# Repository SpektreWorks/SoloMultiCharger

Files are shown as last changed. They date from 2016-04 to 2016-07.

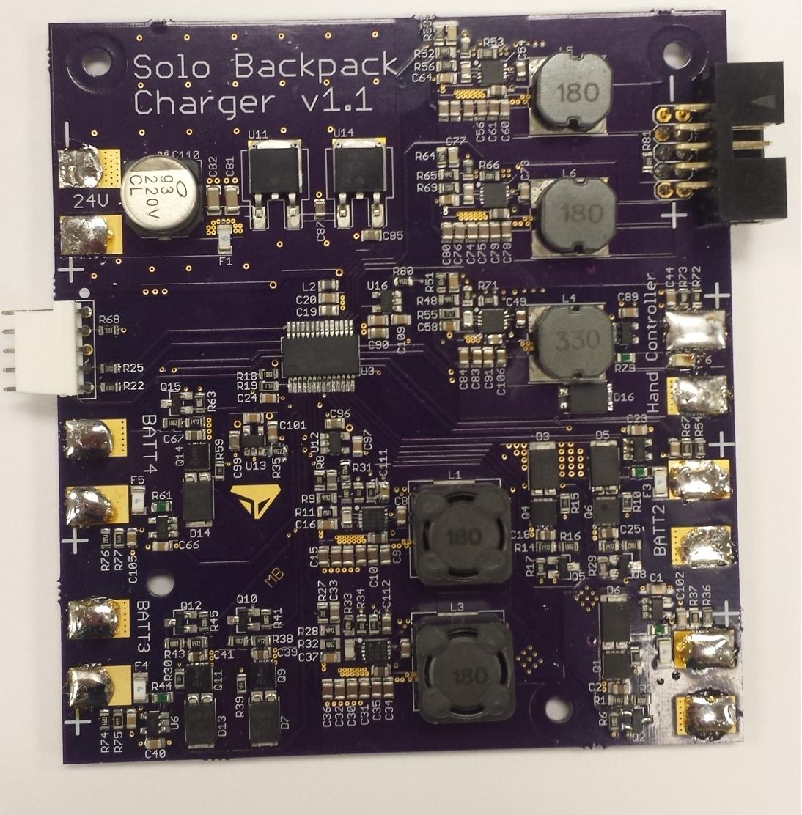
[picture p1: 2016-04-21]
front.jpg

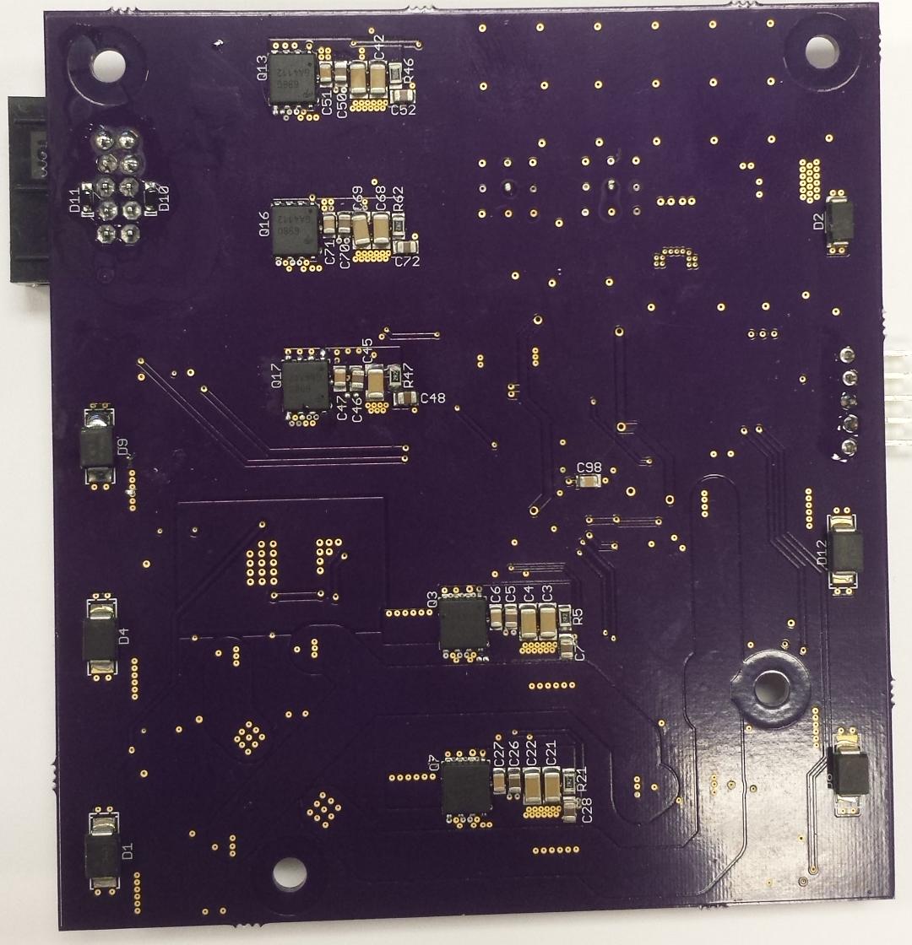
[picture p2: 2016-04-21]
back.jpg

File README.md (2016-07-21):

# SoloMultiCharger
A fully integrated smart circuit to charge up to four Solo Smart Batteries, a Solo hand controller, and two USB devices.

INTRODUCTION

The SpektreWorks Solo Multi-Charger is a multi-battery charging station to be used with the 3DR Solo. It has charging ports for four 3DR Solo Smart Batteries, a Solo hand controller, and two USB devices. SpektreWorks has released all of the design files as open source to the DIY community to build and modify the Multi-Charger. 

The project is made up of a schematic, PCB layout, bill of materials (BOM), and firmware. It is offered as a DIY kit with instructions to make the board, populate it with components, and program the necessary firmware. The schematic and PCB layout are available in Cadsoft Eagle format. The firmware is written in C and compiled with Microchip's XC8 compiler using MPLAB X IDE.

DETAILS

The SpektreWorks Solo Multi-Charger is a single circuit 4-layer PCB that can charge up to four Solo Smart Batteries, the hand controller, and two USB devices. The board requires an external 24VDC power supply capable of at least 5A.

In order to keep the component count and power requirements to a reasonable level, only two batteries charge at a time. Once a battery is done charging, the circuit automatically begins charging the next battery in the queue with no user intervention. The circuit always charges the battery with highest state of charge first. This way, the user only has to wait the shortest possible time to retrieve a fully charged battery.

The Smart Battery and hand controller charge ports are actively current limited. This means that the circuit adjusts the voltage on these ports to not exceed a maximum current value. For the Smart Batteries, the maximum current is 3.3A. The hand controller is 1.5A. These values are adjustable in the firmware, however, it is not recommended to increase those numbers.

The design files in this kit do not include an enclosure of any kind. Users are encouraged to design their own enclosure for the purpose. Keep in mind, however, that this board can generate a lot of heat. Proper heat-sinking and air flow considerations are a very important part of the design.

RELEVANT FILES

PCB/Solo_MultiCharger.sch - Cadsoft Eagle Schematic  
PCB/Solo_MultiCharger.brd - Cadsoft Eagle PCB layout  
PCB/Solo_MultiCharger_BOM.csv - Bill of Materials  
Firmware/Solo_MultiCharger.X/main.c - Source code for charging circuit  
Firmware/Solo_MultiCharger.X/Makefile - Required Makefile for MPLAB  
Firmware/Solo_MultiCharger.X/nbproject - Required directory for MPLAB  
front.jpg - photo of fully assembled front of PCB  
back.jpg - photo of fully assembled back of PCB  

INSTRUCTIONS

**Note: These are extremely abbreviated instructions. We hope that users will suggest what sections need to be elaborated and what sections are fine as they are. As time permits, we will try to expand the instructions until even a relatively inexperienced hobbyist can create their own boards on their own.**

Prerequisites:  
	-Basic familiarity with fabricating PCBs, ordering parts, and soldering  
	-MPLAB X software (free from Microchip) with XC8 compiler (also free)  
	-PICKit3 programming pod  

1. Manufacture the PCB. We did our prototypes at OSHPark.com. We also highly recommend ordering a stencil. This design has a few fine-pitched components that are a little difficult (but not impossible) to solder by hand. Cheap stencils can be ordered from OSHStencils.com.

2. Order the BOM. Every component should be available at digikey.com. If a component is no longer stocked, feel free to contact us and we'll help you find a replacement part.

3. Solder the components to the board.

4. Check the board for shorts. Connect an adjustable current limited power supply and test at 24V. There should only be a few mA of current draw from the supply. If there's more than just a few mA, turn off power and check for solder errors.

5. Check each of the voltages for each switching regulator on the board. For the hand controller and USB outputs, a voltmeter can be applied directly to the charging port pads. The hand controller should show 8.3V and USB should show 5V. The smart battery ports, however, are switched with p-Channel MOSFETs, so they won't always show the required 16.8V. It will be necessary to look at the schematic and probe the capacitors downstream of the inductors of both switching regulators. You should see a steady 16.8V.

5. Open the firmware project in MPLAB X and compile. Confirm there are no compile errors (a couple of “warning (752)” are ok).

6. Connect the board to your computer using a PICKit 3 or equivalent PIC programmer. Program the firmware into the board.

At this point you should be able to connect your 24VDC power supply and start charging batteries, the hand controller, and USB devices. Obviously don't just plug everything in until you've individually tested each port.

Pro Tips:  
	-This board will get hot! Do not place it in an unventilated enclosure. Forced air cooling is always best!  
	-Keep your wires as short as possible. Very long wires can cause large voltage transients when current is suddenly started or stopped.  
	-The four mounting holes are not grounded. If you wish to ground your board to a metal enclosure, you can tap off any solder pad with a negative sign (“-”) next to it.

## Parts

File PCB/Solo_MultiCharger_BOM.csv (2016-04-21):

Qty | Value | Package | Parts
13 | 0.1uF | 805 | C1, C20, C23, C24, C40, C66, C89, C97, C98, C100, C101, C108, C109
10 | 0.1uF 35V | 805 | C6, C27, C44, C47, C51, C71, C102, C103, C104, C105
5 | 0.33uF 50V | 805 | C8, C29, C49, C54, C73
5 | 10uF | 805 | C19, C85, C90, C96, C99
4 | 10uF 16V | 805 | C83, C84, C91, C106
25 | 10uF 35V | 805 | C9, C10, C11, C13, C14, C15, C30, C31, C32, C34, C35, C36, C55, C56, C57, C60, C61, C62, C74, C75, C76, C78, C79, C80, C87
11 | 10uF 35V 1206 | 1206 | C3, C4, C21, C22, C42, C43, C45, C68, C69, C81, C82
1 | 1uF | 805 | C112
16 | 1uF 35V | 805 | C2, C5, C7, C18, C25, C26, C28, C39, C41, C46, C48, C50, C52, C67, C70, C72
1 | 33pF | 805 | C63
6 | 4.7uF | 805 | C92, C93, C94, C95, C107, C111
2 | 43pF | 805 | C65, C88
5 | 4700pF | 805 | C16, C37, C58, C64, C86
2 | 56pF | 805 | C17, C38
2 | 620pF 25V | 805 | C12, C33
3 | 680pF | 805 | C53, C59, C77
1 | UCL1V221MCL6GS | NICHICON_10MM | C110
4 | 1SMB17AT3G | DO-214AA | D1, D4, D8, D12
2 | ESDA8V2-1J | SOD-323 | D10, D11
1 | 1SMA24AT3G | DO-214AC | D2
7 | SBR10E45P5-13 | POWERDI-5 | D3, D5, D6, D7, D13, D14, D16
1 | 1SMB8.5AT3G | DO-214AA | D9
1 | C1F 6 | 1206 | F1
4 | C1F 4 | 1206 | F2, F3, F4, F5
1 | C1F 3 | 1206 | F6
1 | 68021-410HLF | CON_100MIL_2X5 | J2
2 | SRR1280-180M | BOURNS_SRR1280 | L1, L3
1 | MLZ2012M100WT000 | 805 | L2
1 | SRN1060-330M | BOURNS_SRN1060 | L4
2 | SRN1060-180M | BOURNS_SRN1060 | L5, L6
6 | DMP3017SFG-7 | POWERVDFN-8 | Q1, Q4, Q6, Q9, Q11, Q14
6 | 2N7002P | SOT-23-3 | Q2, Q5, Q8, Q10, Q12, Q15
5 | AON6980 | DFN5X6B_8L_EP2_ALPHA&OMEGA | Q3, Q7, Q13, Q16, Q17
5 | 2.2 | 805 | R5, R21, R46, R47, R62
2 | 30 | 805 | R13, R34
4 | 49.9 | 805 | R22, R25, R78, R81
1 | 100 | 805 | R19
1 | 300 | 805 | R68
1 | 1.43k | 805 | R51
2 | 1.62k | 805 | R50, R64
2 | 1.82k 1% | 805 | R12, R33
4 | 10.5k | 805 | R11, R32, R56, R69
11 | 100k | 805 | R2, R7, R10, R15, R23, R30, R31, R35, R39, R59, R80
16 | 10k | 805 | R3, R6, R16, R17, R18, R24, R29, R40, R41, R43, R45, R53, R60, R63, R66, R71
2 | 10k 1% | 805 | R72, R73
5 | 10mR | 805 | R4, R26, R44, R61, R79
6 | 14.7k | 805 | R1, R14, R20, R38, R42, R58
4 | 15k 1% | 805 | R36, R54, R74, R76
2 | 2k | 805 | R8, R27
1 | 3.9k 1% | 805 | R49
5 | 49.9k 1% | 805 | R9, R28, R48, R52, R65
4 | 4.99k 1% | 805 | R37, R67, R75, R77
2 | 6.81k 1% | 805 | R57, R70
1 | 7.5k | 805 | R55
5 | CS30CL | SOT-23-5 | U1, U4, U6, U9, U15
1 | MC78M12CDTG | TO-252-3 | U11
3 | MCP6L01UT-E/OT | SOT-23-5 | U12, U13, U16
1 | MC78M05CDTG | TO-252-3 | U14
5 | MCP19035-AAABE/MF | VFDFN-10_EP | U2, U5, U7, U8, U10
1 | PIC16F1773-I/SS | SSOP-28 | U3

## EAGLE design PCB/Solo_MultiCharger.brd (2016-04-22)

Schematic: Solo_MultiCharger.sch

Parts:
C1, C20, C23, C24, C40, C66, C89, C97, C98, C100, C101, C108, C109: 0.1uF; 0805
C2, C5, C7, C18, C25, C26, C28, C39, C41, C46, C48, C50, C52, C67, C70, C72: 1uF 35V; 0805
C3, C4, C21, C22, C42, C43, C45, C68, C69, C81, C82: 10uF 35V 1206; 1206
C6, C27, C44, C47, C51, C71, C102, C103, C104, C105: 0.1uF 35V; 0805
C8, C29, C49, C54, C73: 0.33uF 50V; 0805
C9, C10, C11, C13, C14, C15, C30, C31, C32, C34, C35, C36, C55, C56, C57, C60, C61, C62, C74, C75, C76, C78, C79, C80, C87: 10uF 35V; 0805
C12, C33: 620pF 25V; 0805
C16, C37, C58, C64, C86: 4700pF; 0805
C17, C38: 56pF; 0805
C19, C85, C90, C96, C99: 10uF; 0805
C53, C59, C77: 680pF; 0805
C63: 33pF; 0805
C65, C88: 43pF; 0805
C83, C84, C91, C106: 10uF 16V; 0805
C92, C93, C94, C95, C107, C111: 4.7uF; 0805
C110: UCL1V221MCL6GS; NICHICON_10MM
C112: 1uF; 0805
D1, D4, D8, D12: 1SMB17AT3G; DO-214AA
D2: 1SMA24AT3G; DO-214AC
D3, D5, D6, D7, D13, D14, D16: SBR10E45P5-13; POWERDI-5
D9: 1SMB8.5AT3G; DO-214AA
D10, D11: ESDA8V2-1J; SOD-323
F1: C1F 6; 1206
F2, F3, F4, F5: C1F 4; 1206
F6: C1F 3; 1206
J1: PIC_ICSP_5PIN; SULLINS_XPXC_5PIN
J2: 68021-410HLF; CON_100MIL_2X5
L1, L3: SRR1280-180M; BOURNS_SRR1280
L2: MLZ2012M100WT000; 0805
L4: SRN1060-330M; BOURNS_SRN1060
L5, L6: SRN1060-180M; BOURNS_SRN1060
P1, P2, P3, P4, P5, P6, P7, P8, P9, P10, P11, P12: SOLDER_PAD_(9); SOLDER_PAD_5X8
Q1, Q4, Q6, Q9, Q11, Q14: DMP3017SFG-7; POWERVDFN-8
Q2, Q5, Q8, Q10, Q12, Q15: 2N7002P; SOT-23-3
Q3, Q7, Q13, Q16, Q17: AON6980; DFN5X6B_8L_EP2_ALPHA&OMEGA
R1, R14, R20, R38, R42, R58: 14.7k; 0805
R2, R7, R10, R15, R23, R30, R39, R59, R80: 100k; 0805
R3, R6, R16, R17, R18, R24, R29, R40, R41, R43, R45, R53, R60, R63, R66, R71: 10k; 0805
R4, R26, R44, R61, R79: 10mR; 0805
R5, R21, R46, R47, R62: 2.2; 0805
R8, R27: 2k; 0805
R9, R28, R48, R52, R65: 49.9k 1%; 0805
R11, R32, R56, R69: 10.5k; 0805
R12, R33: 1.82k 1%; 0805
R13, R34: 30; 0805
R19: 100; 0805
R22, R25, R78, R81: 49.9; 0805
R31, R35: 43k; 0805
R36, R54, R74, R76: 15k 1%; 0805
R37, R67, R75, R77: 4.99k 1%; 0805
R49: 3.9k 1%; 0805
R50, R64: 1.62k; 0805
R51: 1.43k; 0805
R55: 7.5k; 0805
R57, R70: 6.81k 1%; 0805
R68: 300; 0805
R72, R73: 10k 1%; 0805
U1, U4, U6, U9, U15: CS30CL; SOT-23-5
U2, U5, U7, U8, U10: MCP19035-AAABE/MF; VFDFN-10_EP
U3: PIC16F1773-I/SS; SSOP-28
U11: MC78M12CDTG; TO-252-3
U12, U13, U16: MCP6L01UT-E/OT; SOT-23-5
U14: MC78M05CDTG; TO-252-3

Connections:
5V: C1.1, C23.1, C40.1, C66.1, C85.1, C89.1, C90.1, C96.1, C97.1, C99.1, C100.1, C108.1, L2.1, R18.2, R68.2, U1.5 (VCC), U4.5 (VCC), U6.5 (VCC), U9.5 (VCC), U12.5 (V+), U13.5 (V+), U14.3 (VOUT), U15.5 (VCC), U16.5 (V+)
5V_USB1: C55.1, C56.1, C57.1, C60.1, C61.1, C62.1, D11.C, J2.9, L5.2, R50.2, R52.2; also elsewhere on the board
5V_USB2: C74.1, C75.1, C76.1, C78.1, C79.1, C80.1, D10.C, J2.10, L6.2, R64.2, R65.2; also elsewhere on the board
!MCLR: C24.1, J1.1 (!MCLR), R18.1, R19.1
+8.3V: D9.C, F6.1, P9.1, R72.2
+16.8(1)V: C2.1, C9.1, C10.1, C11.1, C13.1, C14.1, C15.1, C18.1, C39.1, L1.P$2 (2), Q1.1 (S), Q1.2 (S), Q1.3 (S), Q4.1 (S), Q4.2 (S), Q4.3 (S), Q9.1 (S), Q9.2 (S), Q9.3 (S), R1.2, R8.2, R9.2, R14.2, R38.2; also elsewhere on the board
+16.8(2)V: C25.1, C30.1, C31.1, C32.1, C34.1, C35.1, C36.1, C41.1, C67.1, L3.P$2 (2), Q6.1 (S), Q6.2 (S), Q6.3 (S), Q11.1 (S), Q11.2 (S), Q11.3 (S), Q14.1 (S), Q14.2 (S), Q14.3 (S), R20.2, R27.2, R28.2, R42.2, R58.2; also elsewhere on the board
+24V: C3.1, C4.1, C5.1, C6.1, C21.1, C22.1, C26.1, C27.1, C42.1, C43.1, C45.1, C46.1, C47.1, C50.1, C51.1, C68.1, C69.1, C70.1, C71.1, C81.1, C82.1, F1.2, Q3.2 (D1), Q3.3 (D1), Q3.4 (D1), Q3.EP1@1 (D1), Q3.EP1@2 (D1), Q7.2 (D1), Q7.3 (D1), Q7.4 (D1), Q7.EP1@1 (D1), Q7.EP1@2 (D1), Q13.2 (D1), Q13.3 (D1), Q13.4 (D1), Q13.EP1@1 (D1), Q13.EP1@2 (D1), Q16.2 (D1), Q16.3 (D1), Q16.4 (D1), Q16.EP1@1 (D1), Q16.EP1@2 (D1), Q17.2 (D1), Q17.3 (D1), Q17.4 (D1), Q17.EP1@1 (D1), Q17.EP1@2 (D1), R5.1, R21.1, R46.1, R47.1, R62.1, U11.1 (VIN)
BATT1: D1.C, F2.1, P2.1, R36.2
BATT1_CURR_SENSE: U1.1 (VOUT), U3.13 (RC2/AN14/C[5,6]IN2-/T5CKI/IOCC2)
BATT1_SRC1: Q2.1 (G), R6.2, U3.9 (RA7/CLKIN/OSC1/IOCA7)
BATT1_V_SENSE: C102.1, R36.1, R37.2, U3.23 (RB2/AN8/OPAIN0-/DAC3OUT1/IOCB2)
BATT2: D4.C, F3.1, P6.1, R54.2
BATT2_CURR_SENSE: U3.14 (RC3/AN15/C[5,6]IN2-/T5CKI/IOCC2), U4.1 (VOUT)
BATT2_SRC1: Q5.1 (G), R17.2, U3.10 (RA6/CLKOUT/C6IN1+/OSC2/IOCA6)
BATT2_SRC2: Q8.1 (G), R29.2, U3.12 (RC1/DAC7OUT1/IOCC1)
BATT2_V_SENSE: C103.1, R54.1, R67.2, U3.22 (RB1/AN10/PRG1IN[0,1]/HIB1/C[1-4]IN3-/OP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)
BATT3: D8.C, F4.1, P8.1, R74.2
BATT3_CURR_SENSE: U3.3 (RA1/AN1/PRG1IN0/IOCA1/C[1-4]IN1-), U6.1 (VOUT)
BATT3_SRC1: Q10.1 (G), R41.2, U3.6 (RA4/OPA1IN0+/DAC4OUT1/T0CKI/IOCA4)
BATT3_SRC2: Q12.1 (G), R45.2, U3.5 (RA3/AN3/VREF+/DAC[1-7]REF0+/C1IN1+/IOCA3)
BATT3_V_SENSE: C104.1, R74.1, R75.2, U3.25 (RB4/AN11/C3IN1+/T5G/IOCB4)
BATT4: D12.C, F5.1, P12.1, R76.2
BATT4_CURR_SENSE: U3.2 (RA0/AN0/IOCA0/C[1-6]IN0-), U9.1 (VOUT)
BATT4_SRC2: Q15.1 (G), R63.2, U3.26 (RB5/AN13/DAC[5,7]REF1-/C4IN2-/T1G/IOCB5)
BATT4_V_SENSE: C105.1, R76.1, R77.2, U3.24 (RB3/AN9/C[1-3]IN2-/OPA2IN0+/IOCB3)
CONTROLLER_ADJ_DAC: C109.1, U3.11 (RC0/DAC5OUT1/T1CKI/T3CKI/T3G/IOCC0), U16.1 (IN+)
CONTROLLER_CURR_SENSE: U3.18 (RC7/AN19/OPA3IN0-/IOCC7), U15.1 (VOUT)
CONTROLLER_EN: R71.2, U3.15 (RC4/AN16/C[5,6]IN3-/T8IN/IOCC4), U7.1 (!SHDN)
CONTROLLER_V_SENSE: C44.1, R72.1, R73.2, U3.21 (RB0/AN12/ZCD/HIB0/C2IN1+/IOCB0)
GND: C1.2, C3.2, C4.2, C5.2, C6.2, C7.2, C9.2, C10.2, C11.2, C13.2, C14.2, C15.2, C19.2, C20.2, C21.2, C22.2, C23.2, C24.2, C26.2, C27.2, C28.2, C30.2, C31.2, C32.2, C34.2, C35.2, C36.2, C40.2, C42.2, C43.2, C44.2, C45.2, C46.2, C47.2, C48.2, C50.2, C51.2, C52.2, C55.2, C56.2, C57.2, C60.2, C61.2, C62.2, C66.2, C68.2, C69.2, C70.2, C71.2, C72.2, C74.2, C75.2, C76.2, C78.2, C79.2, C80.2, C81.2, C82.2, C83.2, C84.2, C85.2, C87.2, C89.2, C90.2, C91.2, C92.2, C93.2, C94.2, C95.2, C96.2, C97.2, C98.2, C99.2, C100.2, C101.2, C102.2, C103.2, C104.2, C105.2, C106.2, C107.2, C108.2, C109.2, C110.-, C111.2, C112.2, D1.A, D2.A, D4.A, D8.A, D9.A, D10.A, D11.A, D12.A, J1.3 (GND), J2.1, J2.2, J2.3, J2.4, P1.1, P4.1, P5.1, P7.1, P10.1, P11.1, Q2.2 (S), Q3.5 (S2), Q3.6 (S2), Q3.7 (S2), Q5.2 (S), Q7.5 (S2), Q7.6 (S2), Q7.7 (S2), Q8.2 (S), Q10.2 (S), Q12.2 (S), Q13.5 (S2), Q13.6 (S2), Q13.7 (S2), Q15.2 (S), Q16.5 (S2), Q16.6 (S2), Q16.7 (S2), Q17.5 (S2), Q17.6 (S2), Q17.7 (S2), R2.1, R6.1, R10.1, R13.1, R15.1, R17.1, R29.1, R30.1, R34.1, R37.1, R39.1, R41.1, R45.1, R49.1, R53.1, R57.1, R59.1, R63.1, R66.1, R67.1, R70.1, R71.1, R73.1, R75.1, R77.1, U1.2 (GND), U2.EP (GND), U3.8 (VSS), U3.19 (VSS), U4.2 (GND), U5.EP (GND), U6.2 (GND), U7.EP (GND), U8.EP (GND), U9.2 (GND), U10.EP (GND), U11.4 (GND/ADJ), U12.2 (V-), U13.2 (V-), U14.4 (GND/ADJ), U15.2 (GND), U16.2 (V-)
unnamed: C7.1, R5.2, R7.2, U2.4 (VIN)
unnamed: C111.1, R7.1, U2.1 (!SHDN)
unnamed: C52.1, R46.2, U8.4 (VIN)
unnamed: C92.1, U2.6 (VCC)
unnamed: D5.A@1 (A), D5.A@2 (A), Q6.5 (D), Q6.6 (D), Q6.7 (D), Q6.8 (D), Q6.EP (D), R10.2
unnamed: C8.1, U2.8 (BOOT)
unnamed: C8.2, L1.P$1 (1), Q3.EP2 (S1D2), U2.9 (PHASE)
unnamed: Q3.1 (G1), U2.10 (HDRV)
unnamed: Q3.8 (G2), U2.7 (LDRV)
unnamed: J1.2 (VCC), R68.1
unnamed: R31.2, U12.3 (IN-), U12.4 (OUT)
unnamed: C87.1, U11.3 (VOUT), U14.1 (VIN)
unnamed: C54.1, U8.8 (BOOT)
unnamed: C54.2, L5.1, Q13.EP2 (S1D2), U8.9 (PHASE)
unnamed: Q13.8 (G2), U8.7 (LDRV)
unnamed: Q13.1 (G1), U8.10 (HDRV)
unnamed: C12.2, C17.2, R9.1, R11.1, R12.2, R31.1, U2.2 (FB)
unnamed: R12.1, R13.2
unnamed: C12.1, R8.1
unnamed: C59.2, C65.2, R52.1, R56.1, R57.2, U8.2 (FB)
unnamed: C72.1, R62.2, U10.4 (VIN)
unnamed: C59.1, R50.1
unnamed: C64.1, C65.1, U8.3 (COMP)
unnamed: C64.2, R56.2
unnamed: C48.1, R47.2, U7.4 (VIN)
unnamed: D3.A@1 (A), D3.A@2 (A), Q4.5 (D), Q4.6 (D), Q4.7 (D), Q4.8 (D), Q4.EP (D), R15.2
unnamed: F3.2, R26.1, U4.4 (VM)
unnamed: C73.1, U10.8 (BOOT)
unnamed: J2.8, R78.2
unnamed: C73.2, L6.1, Q16.EP2 (S1D2), U10.9 (PHASE)
unnamed: Q16.8 (G2), U10.7 (LDRV)
unnamed: C49.1, U7.8 (BOOT)
unnamed: C49.2, L4.1, Q17.EP2 (S1D2), U7.9 (PHASE)
unnamed: Q17.8 (G2), U7.7 (LDRV)
unnamed: Q17.1 (G1), U7.10 (HDRV)
unnamed: J2.7, R81.2
unnamed: C53.1, R51.1
unnamed: C58.1, C63.1, U7.3 (COMP)
unnamed: C58.2, R55.2
unnamed: C2.2, Q1.4 (G), R1.1, R3.2
unnamed: Q2.3 (D), R3.1
unnamed: C16.1, C17.1, U2.3 (COMP)
unnamed: C18.2, Q4.4 (G), R14.1, R16.2
unnamed: C16.2, R11.2
unnamed: C28.1, R21.2, R23.2, U5.4 (VIN)
unnamed: C112.1, R23.1, U5.1 (!SHDN)
unnamed: C95.1, U10.6 (VCC)
unnamed: C107.1, U7.6 (VCC)
unnamed: J2.6, R78.1
unnamed: C29.2, L3.P$1 (1), Q7.EP2 (S1D2), U5.9 (PHASE)
unnamed: Q7.8 (G2), U5.7 (LDRV)
unnamed: Q7.1 (G1), U5.10 (HDRV)
unnamed: C33.2, C38.2, R28.1, R32.1, R33.2, R35.1, U5.2 (FB)
unnamed: R33.1, R34.2
unnamed: C33.1, R27.1
unnamed: C37.1, C38.1, U5.3 (COMP)
unnamed: C37.2, R32.2
unnamed: Q16.1 (G1), U10.10 (HDRV)
unnamed: C77.2, C88.2, R65.1, R69.1, R70.2, U10.2 (FB)
unnamed: Q5.3 (D), R16.1
unnamed: C25.2, Q6.4 (G), R20.1, R24.2
unnamed: Q8.3 (D), R24.1
unnamed: C39.2, Q9.4 (G), R38.1, R40.2
unnamed: Q10.3 (D), R40.1
unnamed: C41.2, Q11.4 (G), R42.1, R43.2
unnamed: Q12.3 (D), R43.1
unnamed: C67.2, Q14.4 (G), R58.1, R60.2
unnamed: Q15.3 (D), R60.1
unnamed: C77.1, R64.1
unnamed: C86.1, C88.1, U10.3 (COMP)
unnamed: C86.2, R69.2
unnamed 104: C83.1, C84.1, C91.1, C106.1, D16.A@1 (A), D16.A@2 (A), L4.2, R48.2, R51.2; also elsewhere on the board
unnamed: R22.1, U3.27 (RB6/DAC[5,7]REF1+/C4IN1+/ICSPCLK)
unnamed: C19.1, C20.1, L2.2, U3.20 (VDD)
unnamed: R19.2, U3.1 (RE3/!MCLR)
unnamed: R25.1, U3.28 (RB7/C5IN1+/DAC[1-7]OUT2/T6IN/ICSPDAT)
unnamed: D6.C, R4.2, U1.3 (VP)
unnamed: D7.C, D13.C, R44.2, U6.3 (VP)
unnamed: D3.C, D5.C, R26.2, U4.3 (VP)
unnamed: D14.C, R61.2, U9.3 (VP)
unnamed: D16.C, R79.2, U15.3 (VP)
unnamed: C29.1, U5.8 (BOOT)
unnamed: C93.1, U5.6 (VCC)
unnamed: C94.1, U8.6 (VCC)
unnamed: R35.2, U13.3 (IN-), U13.4 (OUT)
unnamed: F6.2, R79.1, U15.4 (VM)
unnamed: D6.A@1 (A), D6.A@2 (A), Q1.5 (D), Q1.6 (D), Q1.7 (D), Q1.8 (D), Q1.EP (D), R2.2
unnamed: D7.A@1 (A), D7.A@2 (A), Q9.5 (D), Q9.6 (D), Q9.7 (D), Q9.8 (D), Q9.EP (D), R39.2
unnamed: D13.A@1 (A), D13.A@2 (A), Q11.5 (D), Q11.6 (D), Q11.7 (D), Q11.8 (D), Q11.EP (D), R30.2
unnamed: D14.A@1 (A), D14.A@2 (A), Q14.5 (D), Q14.6 (D), Q14.7 (D), Q14.8 (D), Q14.EP (D), R59.2
unnamed: C53.2, C63.2, R48.1, R49.2, R55.1, R80.1, U7.2 (FB)
unnamed: F4.2, R44.1, U6.4 (VM)
unnamed: F5.2, R61.1, U9.4 (VM)
unnamed: F2.2, R4.1, U1.4 (VM)
unnamed: R80.2, U16.3 (IN-), U16.4 (OUT)
unnamed: J2.5, R81.1
PGC: J1.5 (ICSPCLK), R22.2
PGD: J1.4 (ICSPDAT), R25.2
PWR_IN: C110.+, D2.C, F1.1, P3.1
USB1_EN: R53.2, U3.17 (RC6/AN18/PRG3IN0/C[5,6]IN1-/OPA3OUT/IOC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), U8.1 (!SHDN)
USB2_EN: R66.2, U3.16 (RC5/AN17/OPA3IN0+/T4IN/IOCC5), U10.1 (!SHDN)
V1_ADJ_DAC: C98.1, U3.7 (RA5/AN4/OPA1IN0-/DAC2OUT1/IOCA5), U12.1 (IN+)
V2_ADJ_DAC: C101.1, U3.4 (RA2/AN2/VREF-/DAC[1-7]REF0-/DAC1OUT1/IO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), U13.1 (IN+)

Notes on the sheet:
16.8V for Solo Batteries
5V for USB
8.3V for Hand Controller
BATT1
BATT2
BATT3
BATT4
18uH 4.6A 35mOhm
18uH 3.8A 43mOhm
5V for Logic
10uH
CS30 amplifies voltage drop across sense resistor: Vout = Gain * Rsense * Iload Gain = 100 (for CS30CL) Output swing is restricted to 0.1mV to Vcc-1V. Therefore, with VCC=5V and Rsense=10mOhm, CS30 cannot detect true zero current or current above 4A. Iload Vout 5.5A 4V 5.0A 4V 4.0A 4V 3.0A 3V 2.0A 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
6A Fuse Fast Blow
MCU and PWR IN
DAC signal adjusts current flow in resistor divider to adjust output voltage of regulator by small amounts Vout = (Vfb*R1)/R2 + (0.6*R1-Vdac*R1)/R3 + 0.6 R1 -> Top resistor R2 -> Bottom resistor R3 -> Op Amp resistor When Vdac is set to Vfb (0.6V), output of regulator is unaffected by op amp. Raisi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
DAC signal adjusts current flow in resistor divider to adjust output voltage of regulator by small amounts
20V in 5V out
12V
Assuming all devices on board will draw no more than 100mA, the total power wasted in an LDO is (24V-5V)*100mA = 1.9W. Split the heat dissipation between two bodies by using one LDO to drop from 24V to 12V and a second LDO to drop from 12V to 5V.
33uH 2.8A 72mOhm
10V in 5V out
The MCP19035 has an internally timed soft start, but then both 16.8V sources start up at the same time. Put different RCs on the SHDN pin so they start up differently.
CHANGES: 1. 10uF 35V in 0805 and 1206 packages are about the same price. Might as well change all 1206's to 0805's here.
220uF
ICSP Connector

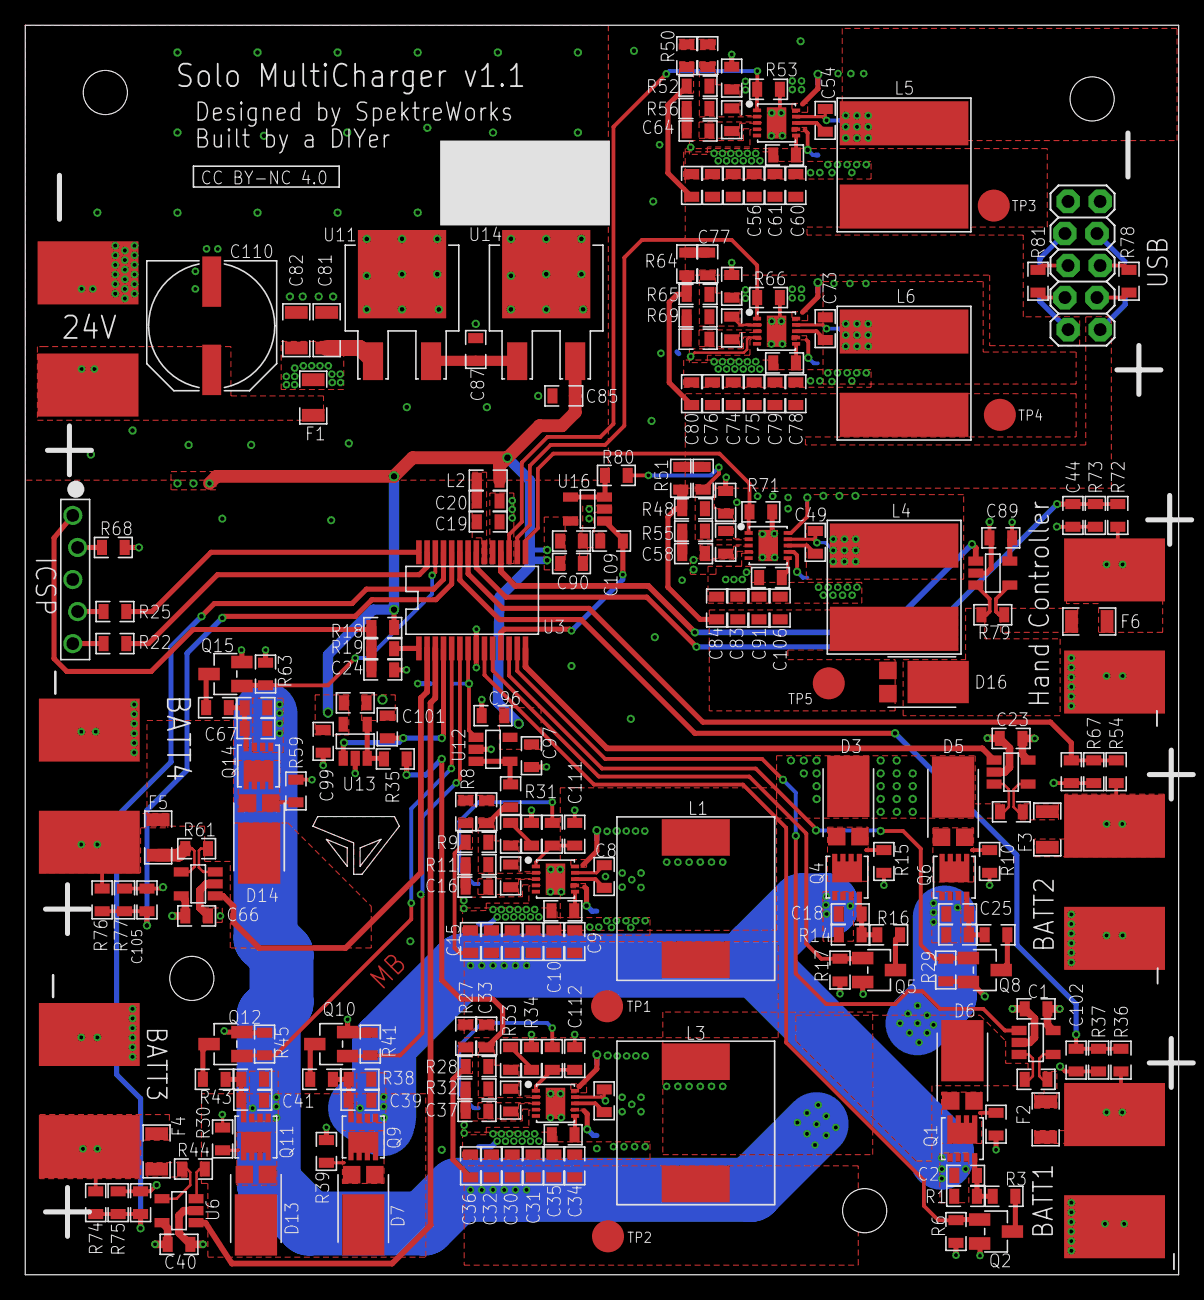
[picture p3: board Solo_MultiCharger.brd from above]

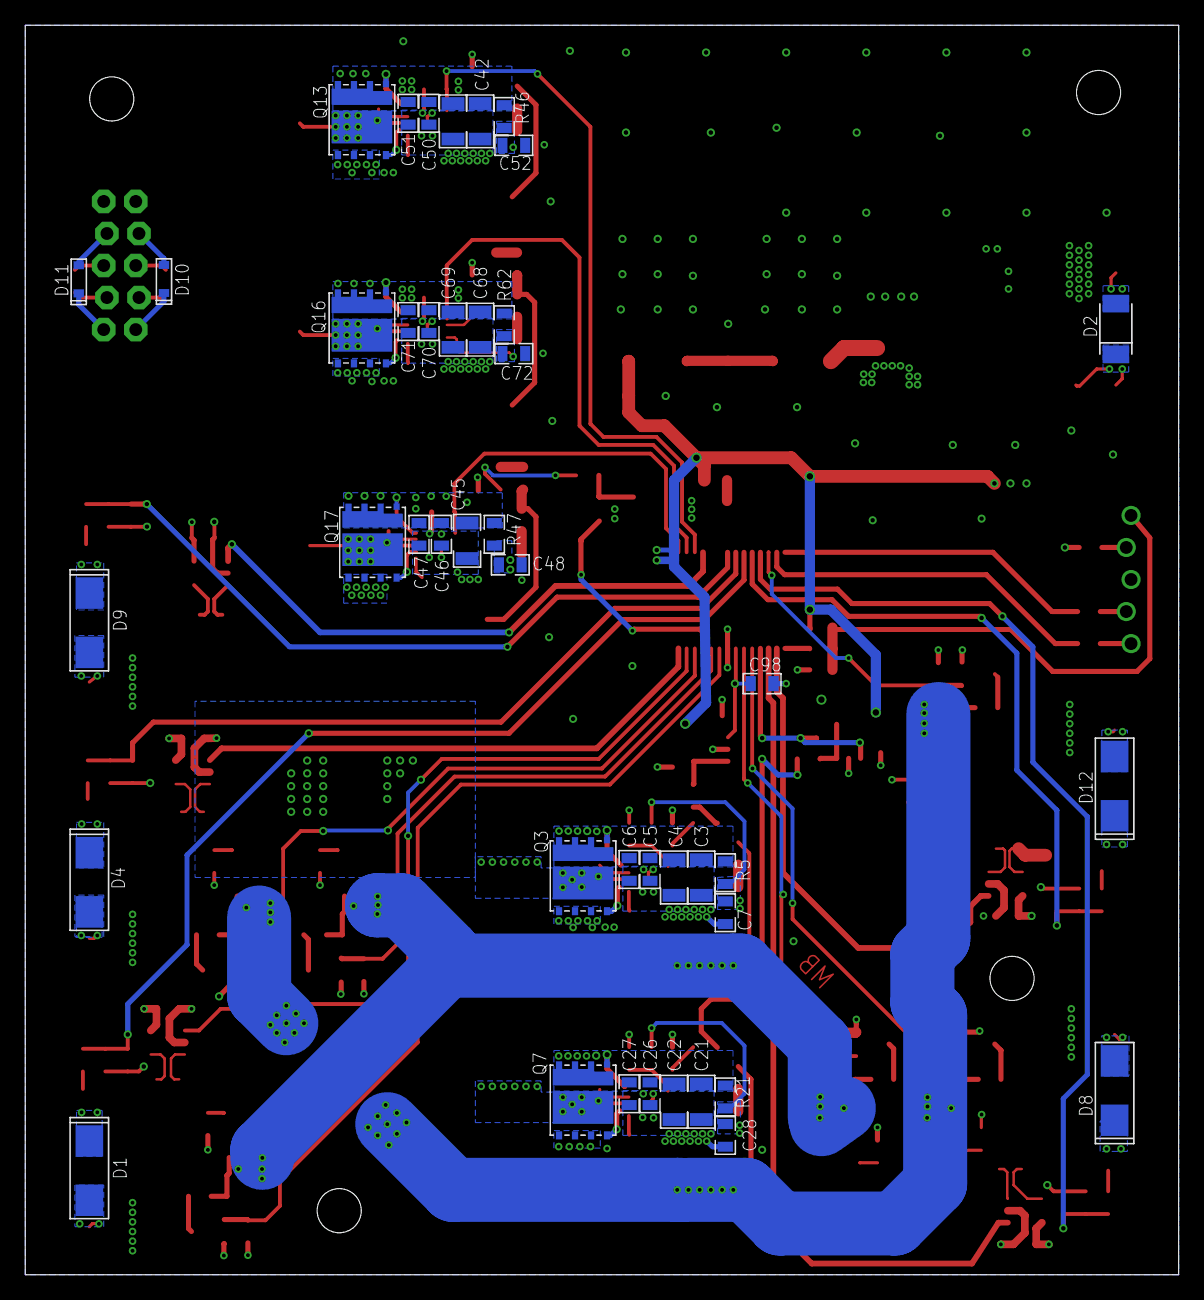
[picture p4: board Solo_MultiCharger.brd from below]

Board: 4 copper layers, 91.4 x 99.1 mm, 276 parts (43 on the bottom side), 134 nets.

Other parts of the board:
TP1, TP2, TP3, TP4, TP5: TESTPAD
U$1, U$2, U$3, U$4: MOUNTING_HOLE_M3

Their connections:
5V_USB1: TP3.TP; also elsewhere on the board
5V_USB2: TP4.TP; also elsewhere on the board
+16.8(1)V: TP1.TP; also elsewhere on the board
+16.8(2)V: TP2.TP; also elsewhere on the board
unnamed 104: TP5.TP; also elsewhere on the board

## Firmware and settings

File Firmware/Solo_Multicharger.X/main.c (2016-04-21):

/*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
    You should have received a copy of the GNU General Public License
    along with this program.  If not, see <http://www.gnu.org/licenses/>.
*****************************************************************************/

#include <xc.h>

typedef unsigned char ubyte;
typedef unsigned short uword;
typedef unsigned long ulong;

// #pragma config statements should precede project file includes.
// Use project enums instead of #define for ON and OFF.

// PIC16F1773 Configuration Bit Settings
// 'C' source line config statements

// CONFIG1
#pragma config FOSC = INTOSC    // Oscillator Selection Bits (INTOSC oscillator: I/O function on CLKIN pin)
#pragma config WDTE = OFF       // Watchdog Timer Enable (WDT disabled)
#pragma config PWRTE = OFF      // Power-up Timer Enable (PWRT disabled)
#pragma config MCLRE = ON       // MCLR Pin Function Select (MCLR/VPP pin function is MCLR)
#pragma config CP = OFF         // Flash Program Memory Code Protection (Program memory code protection is disabled)
#pragma config BOREN = ON       // Brown-out Reset Enable (Brown-out Reset enabled)
#pragma config CLKOUTEN = OFF   // Clock Out Enable (CLKOUT function is disabled. I/O or oscillator function on the CLKOUT pin)
#pragma config IESO = ON        // Internal/External Switchover Mode (Internal/External Switchover Mode is enabled)
#pragma config FCMEN = ON       // Fail-Safe Clock Monitor Enable (Fail-Safe Clock Monitor is enabled)

// CONFIG2
#pragma config WRT = OFF        // Flash Memory Self-Write Protection (Write protection off)
#pragma config PPS1WAY = ON     // Peripheral Pin Select one-way control (The PPSLOCK bit cannot be cleared once it is set by software)
#pragma config ZCD = OFF        // Zero-cross detect disable (Zero-cross detect circuit is disabled at POR)
#pragma config PLLEN = OFF      // Phase Lock Loop enable (4x PLL is enabled when software sets the SPLLEN bit)
#pragma config STVREN = ON      // Stack Overflow/Underflow Reset Enable (Stack Overflow or Underflow will cause a Reset)
#pragma config BORV = LO        // Brown-out Reset Voltage Selection (Brown-out Reset Voltage (Vbor), low trip point selected.)
#pragma config LPBOR = OFF      // Low-Power Brown Out Reset (Low-Power BOR is disabled)
#pragma config LVP = OFF        // Low-Voltage Programming Enable (High-voltage on MCLR/VPP must be used for programming)

#define _XTAL_FREQ 16000000

#define TRUE 1
#define FALSE 0
#define BAY_ON 1
#define BAY_OFF 0

#define BATT1_CURR_SENSE_CHNL 0b001110 
#define BATT2_CURR_SENSE_CHNL 0b001111 
#define BATT3_CURR_SENSE_CHNL 0b000001 
#define BATT4_CURR_SENSE_CHNL 0b000000 
#define BATT1_V_SENSE_CHNL 0b001000
#define BATT2_V_SENSE_CHNL 0b001010
#define BATT3_V_SENSE_CHNL 0b001011
#define BATT4_V_SENSE_CHNL 0b001001
#define CONTROLLER_V_SENSE_CHNL 0b001100
#define CONTROLLER_CURR_SENSE_CHNL 0b010011

#define SRC1_BAY1 LATAbits.LATA7
#define SRC1_BAY2 LATAbits.LATA6
#define SRC1_BAY3 LATAbits.LATA4
#define SRC2_BAY2 LATCbits.LATC1
#define SRC2_BAY3 LATAbits.LATA3
#define SRC2_BAY4 LATBbits.LATB5

#define CONTROLLER_EN LATCbits.LATC4
#define USB1_EN LATCbits.LATC6
#define USB2_EN LATCbits.LATC5

/* Solo Batteries */
#define DAC_MIN_VOLT 0x3FF
#define ADC2VOLTS 0.01958
#define ADC2AMPS 0.0048876
#define VOLTS_THRESH 14.5
#define AMPS_THRESH 0.050
#define MAX_AMPS 3.3
#define MAX_VOLTS 16.8
#define DAC_15V 450

/* Hand Controller Battery */
#define ADC2VOLTS_HC 0.009775
#define ADC2AMPS_HC 0.0048876
#define MAX_AMPS_HC 1.2
#define MAX_VOLTS_HC 8.3
#define DAC_7V_HC 645

#define SRC1 0b00000001
#define SRC2 0b00000010
#define BATT1 0b00000001
#define BATT2 0b00000010
#define BATT3 0b00000100
#define BATT4 0b00001000

/* Globals */

const ubyte batt_v_chnl[] = {0,BATT1_V_SENSE_CHNL,BATT2_V_SENSE_CHNL,BATT3_V_SENSE_CHNL,BATT4_V_SENSE_CHNL};
const ubyte batt_curr_chnl[] = {0,BATT1_CURR_SENSE_CHNL,BATT2_CURR_SENSE_CHNL,BATT3_CURR_SENSE_CHNL,BATT4_CURR_SENSE_CHNL};

//Master global clock. Increments every overflow of Timer1 (50ms).
volatile ulong clock = 0;

/* All arrays have an extra unit of length so that
 * we can index starting from 1 instead of 0. This
 * way code matches schematic and PCB. */

//Voltage source structure
volatile struct
{
    ubyte in_use;    //whether voltage source is actively charging a battery (t/f)
    ubyte servicing; //which battery bay the voltage source is servicing (1 or 2)
    uword dac;       //the current DAC value controlling the voltage source
}vsrc[4];

//Battery bay structure
volatile struct
{
    ubyte occupied;       //whether a battery is occupying the bay (t/f)
    ubyte setToCharge;    //flag to indicate battery should be charging if it's not already (t/f)
    ubyte charging;       //flag to indicate battery is actively charging
    float measured_volts; //measured voltage at battery bay
    float measured_amps;  //measured current into battery
    ubyte fault;
}bay[5];

/* Functions */

void InitPorts(void)
{
    LATA = 0;
    LATB = 0;
    LATC = 0;

    TRISAbits.TRISA0 = 1; //BATT4_CURR_SENSE
    TRISAbits.TRISA1 = 1; //BATT3_CURR_SENSE
    TRISAbits.TRISA2 = 0; //V2_ADJ_DAC
    TRISAbits.TRISA3 = 0; //BATT3_SRC2
    TRISAbits.TRISA4 = 0; //BATT3_SRC1
    TRISAbits.TRISA5 = 0; //V1_ADJ_DAC
    TRISAbits.TRISA6 = 0; //BATT2_SRC1
    TRISAbits.TRISA7 = 0; //BATT1_SRC1

    TRISBbits.TRISB0 = 1; //CONTROLLER_V_SENSE
    TRISBbits.TRISB1 = 1; //BATT2_V_SENSE
    TRISBbits.TRISB2 = 1; //BATT1_V_SENSE
    TRISBbits.TRISB3 = 1; //BATT4_V_SENSE
    TRISBbits.TRISB4 = 1; //BATT3_V_SENSE
    TRISBbits.TRISB5 = 0; //BATT4_SRC2
    TRISBbits.TRISB6 = 1; //PGC
    TRISBbits.TRISB7 = 1; //PGD

    TRISCbits.TRISC0 = 0; //CONTROLLER_ADJ_DAC
    TRISCbits.TRISC1 = 0; //BATT2_SRC2
    TRISCbits.TRISC2 = 1; //BATT1_CURR_SENSE
    TRISCbits.TRISC3 = 1; //BATT2_CURR_SENSE
    TRISCbits.TRISC4 = 0; //CONTROLLER_EN
    TRISCbits.TRISC5 = 0; //USB2_EN
    TRISCbits.TRISC6 = 0; //USB1_EN
    TRISCbits.TRISC7 = 1; //CONTROLLER_CURR_SENSE

    ANSELA = 0;
    ANSELAbits.ANSA0 = 1; //BATT4_CURR_SENSE (AN0)
    ANSELAbits.ANSA1 = 1; //BATT3_CURR_SENSE (AN1)

    ANSELB = 0;
    ANSELBbits.ANSB0 = 1; //CONTROLLER_V_SENSE (AN12)
    ANSELBbits.ANSB1 = 1; //BATT2_V_SENSE (AN10)
    ANSELBbits.ANSB2 = 1; //BATT1_V_SENSE (AN8)
    ANSELBbits.ANSB3 = 1; //BATT4_V_SENSE (AN9)
    ANSELBbits.ANSB4 = 1; //BATT3_V_SENSE (AN11)

    ANSELC = 0;
    ANSELCbits.ANSC2 = 1; //BATT1_CURR_SENSE (AN14)
    ANSELCbits.ANSC3 = 1; //BATT2_CURR_SENSE (AN15)
    ANSELCbits.ANSC7 = 1; //CONTROLLER_CURR_SENSE (AN16)
}

void InitTimer1(void)
{
    //50ms tic timer, 16-bit
    T1CONbits.CS = 0b00; //FOSC/4
    T1CONbits.CKPS = 0b11; //1:8 prescaler
    T1CONbits.OSCEN = 0;
    PIR1bits.TMR1IF = 0;
    TMR1H = 0x9E;
    TMR1L = 0x57;
    PIE1bits.TMR1IE = 0;
    T1CONbits.ON = 1;
}

void InitADC(void)
{
    ADCON1bits.ADFM = 1; //Right justified
    ADCON1bits.ADCS = 0b100; //FOSC/4
    ADCON1bits.ADNREF = 0; //VREF- is VSS 
    ADCON1bits.ADPREF = 0b00; //VREF+ is VDD
    ADCON0bits.ADON = 1;
}

uword GetADC(ubyte chnl)
{
    //Return a single ADC read from the specified channel (chnl)
    uword result;

    ADCON0bits.CHS = chnl;

    __delay_us(10);
    ADCON0bits.GO = 1;
    while(ADCON0bits.GO);
    result = (((uword)ADRESH)<<8) + ((uword)ADRESL);
    return result; 
}

uword GetADC16(ubyte chnl)
{
    //Return the average of 16 subsequent ADC reads
    uword result;
    ADCON0bits.CHS = chnl;
    
    uword sum = 0;
    for(ubyte a=0;a<16;a++)
    {
        __delay_us(10);
        ADCON0bits.GO = 1;
        while(ADCON0bits.GO);
        sum += ((((uword)ADRESH)<<8) + ((uword)ADRESL));
    }
    result = sum >> 4;
    return result; 
}

void UpdateBayData(ubyte b)
{
    //Check voltage and current flow at bay b. Update whether bay b
    //is occupied with a battery or not. A newly detected battery
    //that is showing a voltage within 200mv of max is considered
    //fully charged and is ignored.

    bay[b].measured_volts = (float)GetADC16(batt_v_chnl[b])*ADC2VOLTS;
    bay[b].measured_amps = (float)GetADC16(batt_curr_chnl[b])*ADC2AMPS;

    if ( !bay[b].occupied )
    {
        //Clean up, just in case one of these is hanging
        bay[b].charging = FALSE;
        bay[b].setToCharge = FALSE;

        if ( bay[b].measured_volts > (MAX_VOLTS-0.2) )
        {
            //1. Fully charged battery (ignore it)
            return;
        }

        if ( bay[b].measured_volts > VOLTS_THRESH )
        {
            //2. Uncharged battery just plugged in
            bay[b].occupied = TRUE;
            return;
        }
    }
    else //bay[b].occupied == TRUE
    {
        if ( (bay[b].measured_volts > VOLTS_THRESH) && (bay[b].measured_amps > AMPS_THRESH) )
        {
            //3. Battery charging
            bay[b].charging = TRUE;
            return;
        }

        if ( (bay[b].measured_volts > VOLTS_THRESH) && (bay[b].measured_amps < AMPS_THRESH) )
        {
            //4. Battery done charging or battery removed while charging
            bay[b].charging = FALSE;
            bay[b].setToCharge = FALSE;
            bay[b].occupied = FALSE;
            return;
        }
    }
}

void SetDAC(ubyte s, uword val)
{
    //Voltage is changed on the voltage sources by making very
    //small adjustments to the center tap of the feedback resistor
    //networks on the switching regulators. The small adjustments
    //are accomplished using buffered DACs, which are controlled here.

    //Reject nonsense values
    if ( val > 0x3FF )return;

    switch(s)
    {
        case 1:
            DAC2REFH = (ubyte)(val>>8);
            DAC2REFL = (ubyte)val;
            DACLDbits.DAC2LD = 1;
            vsrc[1].dac = val;
            break;
        case 2:
            DAC1REFH = (ubyte)(val>>8);
            DAC1REFL = (ubyte)val;
            DACLDbits.DAC1LD = 1;
            vsrc[2].dac = val;
            break;
        case 3: 
            DAC5REFH = (ubyte)(val>>8);
            DAC5REFL = (ubyte)val;
            DACLDbits.DAC5LD = 1;
            vsrc[3].dac = val;
            break;
    }
}

void InitDACs(void)
{
    //Source 1
    DAC2CON0bits.FM = 0; //DAC2 reference selection right justified
    DAC2CON0bits.PSS = 0b00; //VDD is positive source
    DAC2CON0bits.NSS = 0b00; //GND is negative source
    SetDAC(1,0x3FF); //Initialize to highest DAC voltage, which corresponds to lowest regulator output  
    DACLDbits.DAC2LD = 1; //Load in new DAC value
    DAC2CON0bits.OE1 = 1; //DAC2OUT1 enabled
    DAC2CON0bits.EN = 1;
    
    //Source 2
    DAC1CON0bits.FM = 0;
    DAC1CON0bits.PSS = 0b00;
    DAC1CON0bits.NSS = 0b00;
    SetDAC(2,0x3FF);
    DACLDbits.DAC1LD = 1;
    DAC1CON0bits.OE1 = 1;
    DAC1CON0bits.EN = 1;
    
    //Controller source
    DAC5CON0bits.FM = 0;
    DAC5CON0bits.PSS = 0b00;
    DAC5CON0bits.NSS = 0b00;
    SetDAC(3,0x3FF);
    DACLDbits.DAC5LD = 1;
    DAC5CON0bits.OE1 = 1;
    DAC5CON0bits.EN = 1;
}

void InitStructs(void)
{
    //vsrc[0] and bay[0] are unused (see comment at top of code)
    //but initialize to defaults here anyway.
    for(ubyte a=0;a<=3;a++)
    {
        vsrc[a].in_use = FALSE;
        vsrc[a].servicing = 0;
    }

    for(ubyte a=0;a<=4;a++)
    {
        bay[a].occupied = FALSE;
        bay[a].setToCharge = FALSE;
        bay[a].charging = FALSE;
        bay[a].measured_volts = 0.0;
        bay[a].measured_amps = 0.0;
        bay[a].fault = 0;
    }
}

void Enable_HC_and_USB(void)
{
    //Turn on PFETs for the hand controller and both USB ports
    CONTROLLER_EN = TRUE;
    USB1_EN = TRUE;
    USB2_EN = TRUE;
}

void Deactivate(ubyte s)
{
    //Turn off selected source to all batteries at once. There should
    //never be a time that one source is servicing more than one battery.
    //This function provides a common way to automatically update the vsrc
    //structures with correct values.
    SetDAC(s,DAC_MIN_VOLT);
    vsrc[s].servicing = 0;
    vsrc[s].in_use = FALSE;
    switch(s)
    {
        case 1:
            SRC1_BAY1 = FALSE;
            SRC1_BAY2 = FALSE;
            SRC1_BAY3 = FALSE;
            break;
        case 2:
            SRC2_BAY2 = FALSE;
            SRC2_BAY3 = FALSE;
            SRC2_BAY4 = FALSE;
            break;
    }
}

void Activate(ubyte s, ubyte b)
{
    //Low level battery bay control. No error checking done.
    vsrc[s].servicing = b;
    vsrc[s].in_use = TRUE;
    switch(s)
    {
        case 1:
            switch(b)
            {
                case 1: SRC1_BAY1 = TRUE;break;
                case 2: SRC1_BAY2 = TRUE;break;
                case 3: SRC1_BAY3 = TRUE;break;
            }
            break;
        case 2:
            switch(b)
            {
                case 2: SRC2_BAY2 = TRUE;break;
                case 3: SRC2_BAY3 = TRUE;break;
                case 4: SRC2_BAY4 = TRUE;break;
            }
            break;
    }
}

void SwapVsrc(ubyte vsrc_from, ubyte vsrc_to, ubyte b)
{
    //Seemlessly swap which voltage source is servicing a specific battery bay.
    //For example, if voltage source 1 is currently servicing bay 2, the following
    //function call will deactivate voltage source 1 and activate voltage source 2
    //for bay 2 instead: SwapVsrc(1,2,2);

    if ( (b == 1) || (b == 4) )
    {
        //This should never happen because only source 1 can service
        //bay 1 and only source 2 can service bay 4, so these
        //batteries cannot have their sources swapped.
        return;
    }

    if ( (vsrc_from > 2) || (vsrc_to > 2) )
    {
        //Only two voltage sources available for swapping
        return;
    }

    switch(vsrc_from)
    {
        case 1:
            //Set source 2 voltage equal to source 1 voltage.
            SetDAC(2,vsrc[1].dac);

            //Turn on source 2 for specified battery
            switch(b)
            {
                case 2: Activate(2,2);break;
                case 3: Activate(2,3);break;
            }

            //PFET takes a few 10s of milliseconds to fully turn on
            __delay_ms(100);

            //Turn off source 1 from specified battery
            Deactivate(1);
            break;

        case 2:
            //Set source 1 voltage equal to source 2 voltage.
            SetDAC(1,vsrc[2].dac);

            //Turn on source 1 for specified battery
            switch(b)
            {
                case 2: Activate(1,2);break;
                case 3: Activate(1,3);break;
            }

            //PFET takes a few 10s of milliseconds to fully turn on
            __delay_ms(100);

            //Turn off source 2 from specified battery
            Deactivate(2);
            break;
    }
    //There was a voltage spike observed on the "other" port
    //(i.e., if bay 3 has a battery, then a spike was observed
    //on an unconnected bay 2). This function (SwapVsrc) is immediately
    //followed by an Activate() function call, which was apparently
    //turning on the other port before the previous port was fully
    //turned off. This delay appears to remove the spike.
    __delay_ms(20);
}

void BayControl(ubyte b, ubyte bay_onoff)
{
    //High level control of each battery bay with error checking.
    //b: battery bay number
    //bay_onoff: On or off control

    //To minimize hardware components, only two voltage sources serve all
    //four battery bays:
    //  Voltage Source 1 can serve bays 1, 2, and 3.
    //  Voltage Source 2 can serve bays 2, 3, and 4.
    //This introduces the need for active switching of the voltage source between
    //battery bays. If, for example, a battery is charging in bay 2 using voltage 
    //source 1 and then a second battery is placed in bay 1, then voltage source 1
    //must switch over to the new battery and voltage source 2 must take over charging
    //the first battery.

    //If a fault has already been detected on the requested battery bay,
    //just ignore request and exit.
    if ( bay[b].fault )
    {
        return;
    }

    if ( bay_onoff )
    {
        if ( vsrc[1].in_use && vsrc[2].in_use )
        {
            //Two batteries are already charging. Can't do anything more.
            return;
        }

        if ( (vsrc[1].servicing == b) || (vsrc[2].servicing == b) )
        {
            //Requested bay is already being serviced by one of the voltage sources.
            return;
        }

        if ( b == 1 )
        {
            if ( vsrc[1].in_use )
            {
                //Only source 1 can service battery bay 1, so have source 2 take
                //over whichever battery bay source 1 is currently servicing
                SwapVsrc(1,2,vsrc[1].servicing);
            }
            Activate(1,1);
        }
        else if ( (b==2) || (b==3) )
        {
            if ( vsrc[1].in_use )
            {
                Activate(2,b);
            }
            else if ( !vsrc[1].in_use )
            {
                Activate(1,b);
            }
        }
        else if ( b == 4 )
        {
            if ( vsrc[2].in_use )
            {
                //Only source 2 can service battery bay 4, so have source 1 take
                //over whichever battery bay source 2 is currently servicing
                SwapVsrc(2,1,vsrc[2].servicing);
            }
            Activate(2,4);
        }
    }
    else if ( !bay_onoff ) 
    {
        //Deactivating a battery bay results in deacticting the source
        //that was connected to it. So deactivate the whole source here.
        if ( vsrc[1].servicing == b )
        {
            Deactivate(1);
        }
        else if ( vsrc[2].servicing == b )
        {
            Deactivate(2);
        }
    }
}

ubyte NumBaysSetToCharge(void)
{
    return bay[1].setToCharge + bay[2].setToCharge + bay[3].setToCharge + bay[4].setToCharge;
}

ubyte NumBaysOccupied(void)
{
    return bay[1].occupied + bay[2].occupied + bay[3].occupied + bay[4].occupied;
}

ubyte NextToCharge(void)
{
    //Returns the index of the battery bay with the highest measured voltage.
    //A battery that is already charging will be skipped over.
    float highvolts = 0.0;
    ubyte highbay = 0;

    for(ubyte b=1;b<=4;b++)
    {
        if ( !bay[b].setToCharge )
        {
            if ( bay[b].occupied )
            {
                if ( bay[b].measured_volts > highvolts ) 
                {
                    highvolts = bay[b].measured_volts;
                    highbay= b;
                }
            }
        }
    }
    return highbay;
}

void SetToCharge(ubyte b)
{
    //The setToCharge flag is true as soon as a battery has been queued up to charge
    //and remains true for as long as the battery is actively charging.
    bay[b].setToCharge = TRUE;
}

void FaultCheck(void)
{
    float volts;
    float amps;
    static ubyte overcurrent[5] = {0,0,0,0,0};

    for(ubyte b=1;b<=4;b++)
    {
        //Dead short condition
        if ( (bay[b].measured_volts < VOLTS_THRESH) && (bay[b].measured_amps > AMPS_THRESH) )
        {
            bay[b].fault = 1;
        }

        //Another short condition
        if ( (bay[b].occupied == FALSE) && (bay[b].measured_amps > AMPS_THRESH) )
        {
            bay[b].fault = 2;
        }

        //Over-current condition
        //Allow up to 250ms of over-current before throwing fault
        if ( bay[b].measured_amps > 3.5 )
        {
            overcurrent[b]++;
            if ( overcurrent[b] >= 5 )
            {
                bay[b].fault = 3;
            }
        }
        else
        {
            overcurrent[b] = 0;
        }

        //Over-voltage condition
        if ( bay[b].measured_volts > 18.0 )
        {
            bay[b].fault = 4;
        }

        //If any fault condition is detected on a bay, disable
        //all voltage sources associated with that bay.
        if ( bay[b].fault )
        {
            switch(b)
            {
                case 1:
                    SRC1_BAY1 = FALSE;
                    break;
                case 2:
                    SRC1_BAY2 = FALSE;
                    SRC2_BAY2 = FALSE;
                    break;
                case 3:
                    SRC1_BAY3 = FALSE;
                    SRC2_BAY3 = FALSE;
                    break;
                case 4:
                    SRC2_BAY4 = FALSE;
                    break;
            }
            bay[b].occupied = FALSE;
            bay[b].setToCharge = FALSE;
            bay[b].charging = FALSE;

            BayControl(b,BAY_OFF);
        }
    }    
}

void IncrementVolts(ubyte b)
{
    //The smaller the DAC value, the higher the output of the voltage source
    if ( vsrc[1].servicing == b )
    {
        if ( vsrc[1].dac > 0 )
        {
            SetDAC(1,vsrc[1].dac-5);
        }
    }
    else if ( vsrc[2].servicing == b )
    {
        if ( vsrc[2].dac > 0 )
        {
            SetDAC(2,vsrc[2].dac-5);
        }
    }
}

void DecrementVolts(ubyte b)
{
    //The larger the DAC value, the lower the output of the voltage source
    if ( vsrc[1].servicing == b )
    {
        if ( vsrc[1].dac < DAC_MIN_VOLT )
        {
            SetDAC(1,vsrc[1].dac+5);
        }
    }
    else if ( vsrc[2].servicing == b )
    {
        if ( vsrc[2].dac < DAC_MIN_VOLT )
        {
            SetDAC(2,vsrc[2].dac+5);
        }
    }
}
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
void main(void)
{
    //FOSC: 16MHz INTSOC
    OSCCONbits.IRCF = 0b1111;

    //Initialize port pins
    InitPorts();

    //Tic timer
    InitTimer1();

    //Initialize ADC
    InitADC();

    //Initialize DACs 
    InitDACs();

    //Initialize source and bay structures
    InitStructs();

    //Enable hand controller and USB power supplies
    Enable_HC_and_USB();

    while(1)
    {
        ScanForBatteries();
        FaultCheck();
        ChargeControl();
        ChargeControlHC();

        while(!PIR1bits.TMR1IF);
        PIR1bits.TMR1IF = 0;
        clock++;
        //50ms tic timer
        TMR1H = 0x9E;
        TMR1L = 0x57;
    }
}

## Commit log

2016-04-21 Increase min via drill to 12mil
    [Solo_MultiCharger.brd]
2016-04-21 Added reference to 4-layer board
2016-04-22 A few small layout changes
    [Solo_MultiCharger.brd]

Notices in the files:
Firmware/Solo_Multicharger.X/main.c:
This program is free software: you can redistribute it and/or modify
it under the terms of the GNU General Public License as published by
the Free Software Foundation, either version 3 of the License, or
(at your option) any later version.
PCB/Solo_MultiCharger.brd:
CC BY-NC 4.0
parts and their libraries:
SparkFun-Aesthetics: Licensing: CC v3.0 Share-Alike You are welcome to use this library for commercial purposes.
